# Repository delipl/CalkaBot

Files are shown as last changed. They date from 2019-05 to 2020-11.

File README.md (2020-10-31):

# CalkaBot

CałkaBots are robots created by Jakub Kuziemski and Jakub Delicat. The first one CałkaBot 1.0 was made in 2018 for miniSUMO competition in UTP in Bydgoszcz. We were first grade students then, and we weren't experienced enough, so it was a huge surprise when we got to a semifinal group. The second one, CałkaBot 2.0, was made the following year and won a special prize in Bydgoszcz. We have been appreciated for the progress and for a PCB board project made by Deli. With both robots, improved to versions 1.1 and 2.1, we have gone to Baltic Robo Battles, to face up univeristy students. We weren't surprised when we have lost most of the battles, but CałkaBots were hard opponent many times. We have even managed to win some of the battles against students of technical universities.

# Our Team
- [Jakub Kuziemski (@JakubKivi)](https://github.com/JakubKivi)
- [Jakub Delicat (@delipl)](https://github.com/delipl)
- [Adam Wieczarek (@AWieczarek)](https://github.com/AWieczarek)

CałkaBots 3d0 and 3k0 are comming.

# Hardware and software tips
To program BluePill from hid bootloader it is nessesery to refresh flash data in STM32CUBE

To run STM32CubeProgrammer on linux it is nessesery to install java zulu

Ahh.. To run EAGLE on linux it is nessesery to copy library to $EAGLE/lib folder 
`sudo cp /usr/lib/x86_64-linux-gnu/libxcb-dri3.so.0 lib/
`

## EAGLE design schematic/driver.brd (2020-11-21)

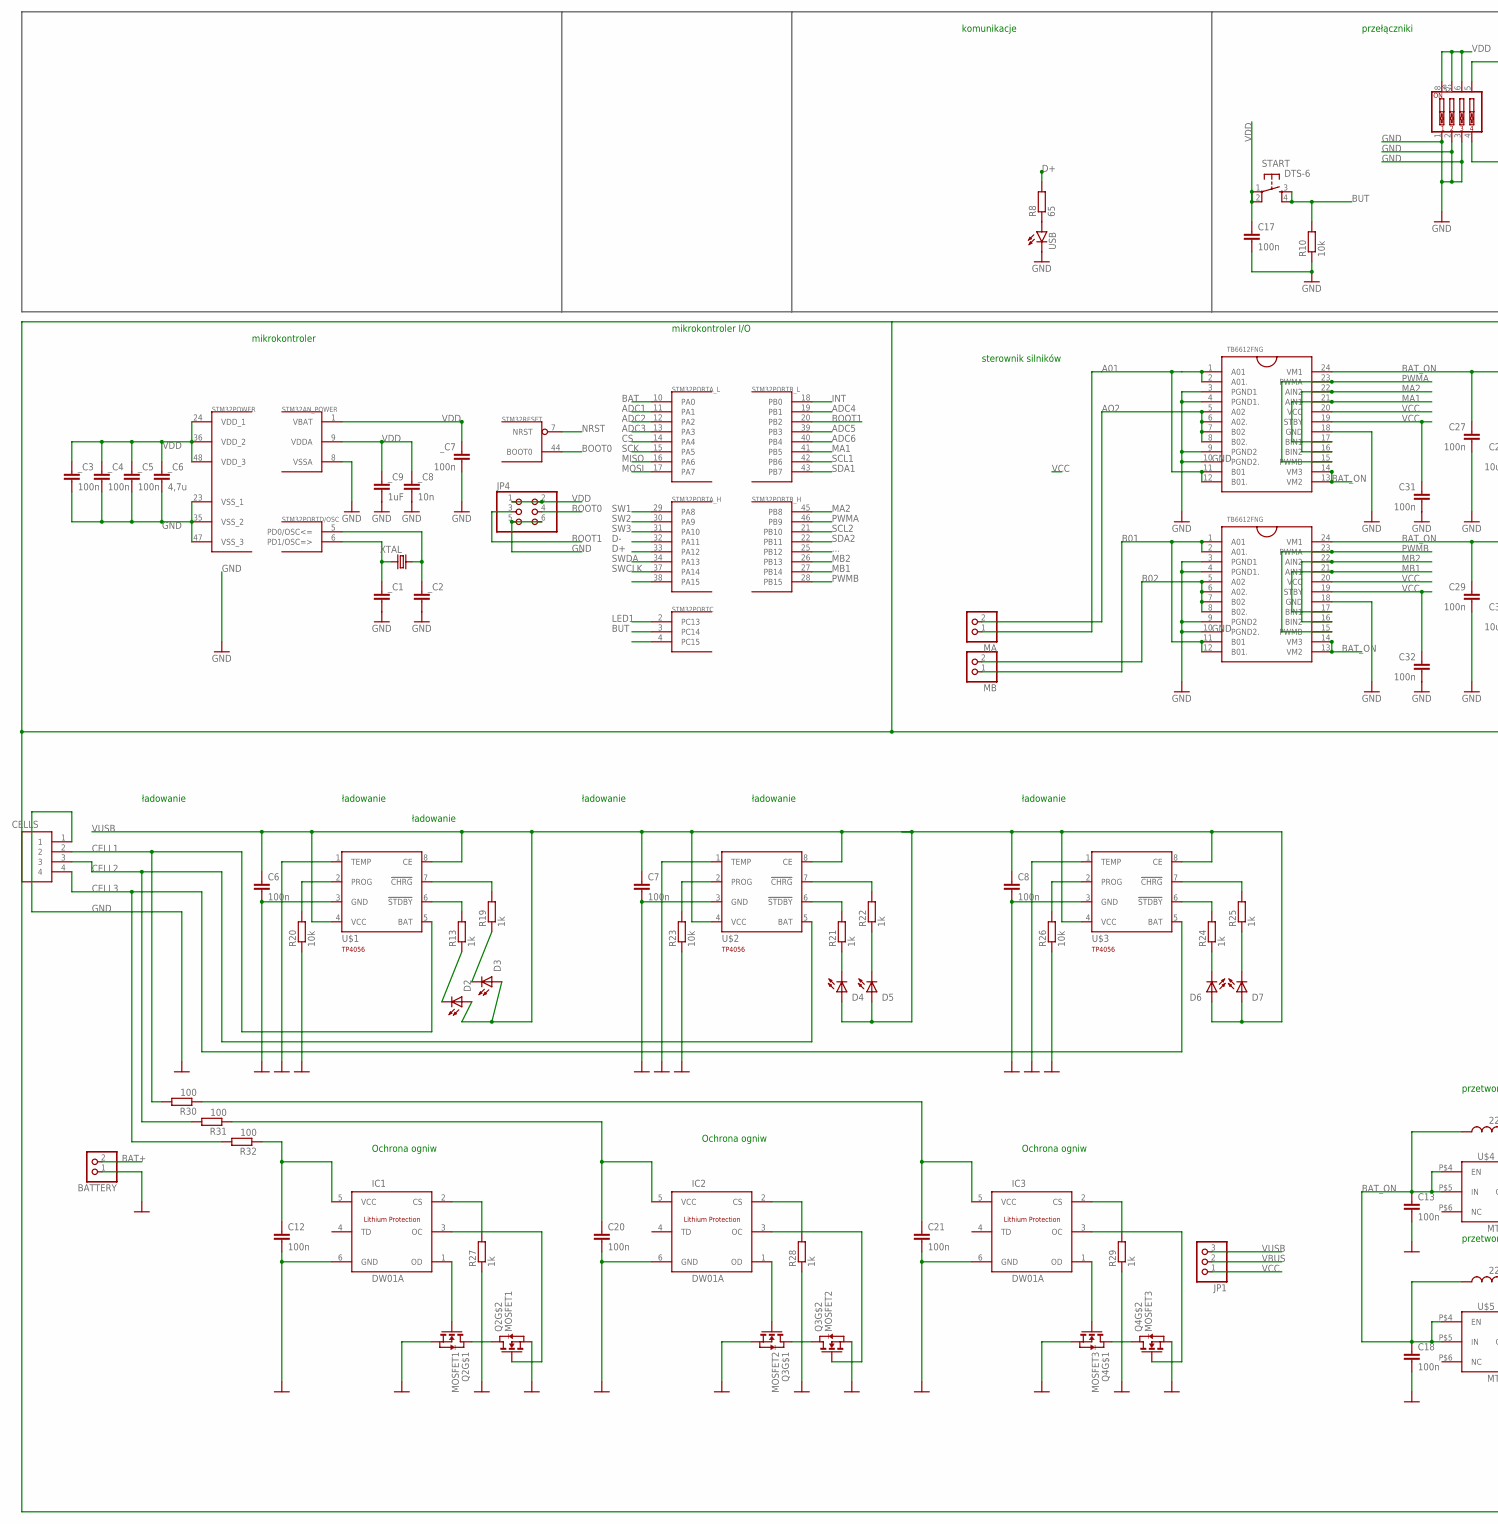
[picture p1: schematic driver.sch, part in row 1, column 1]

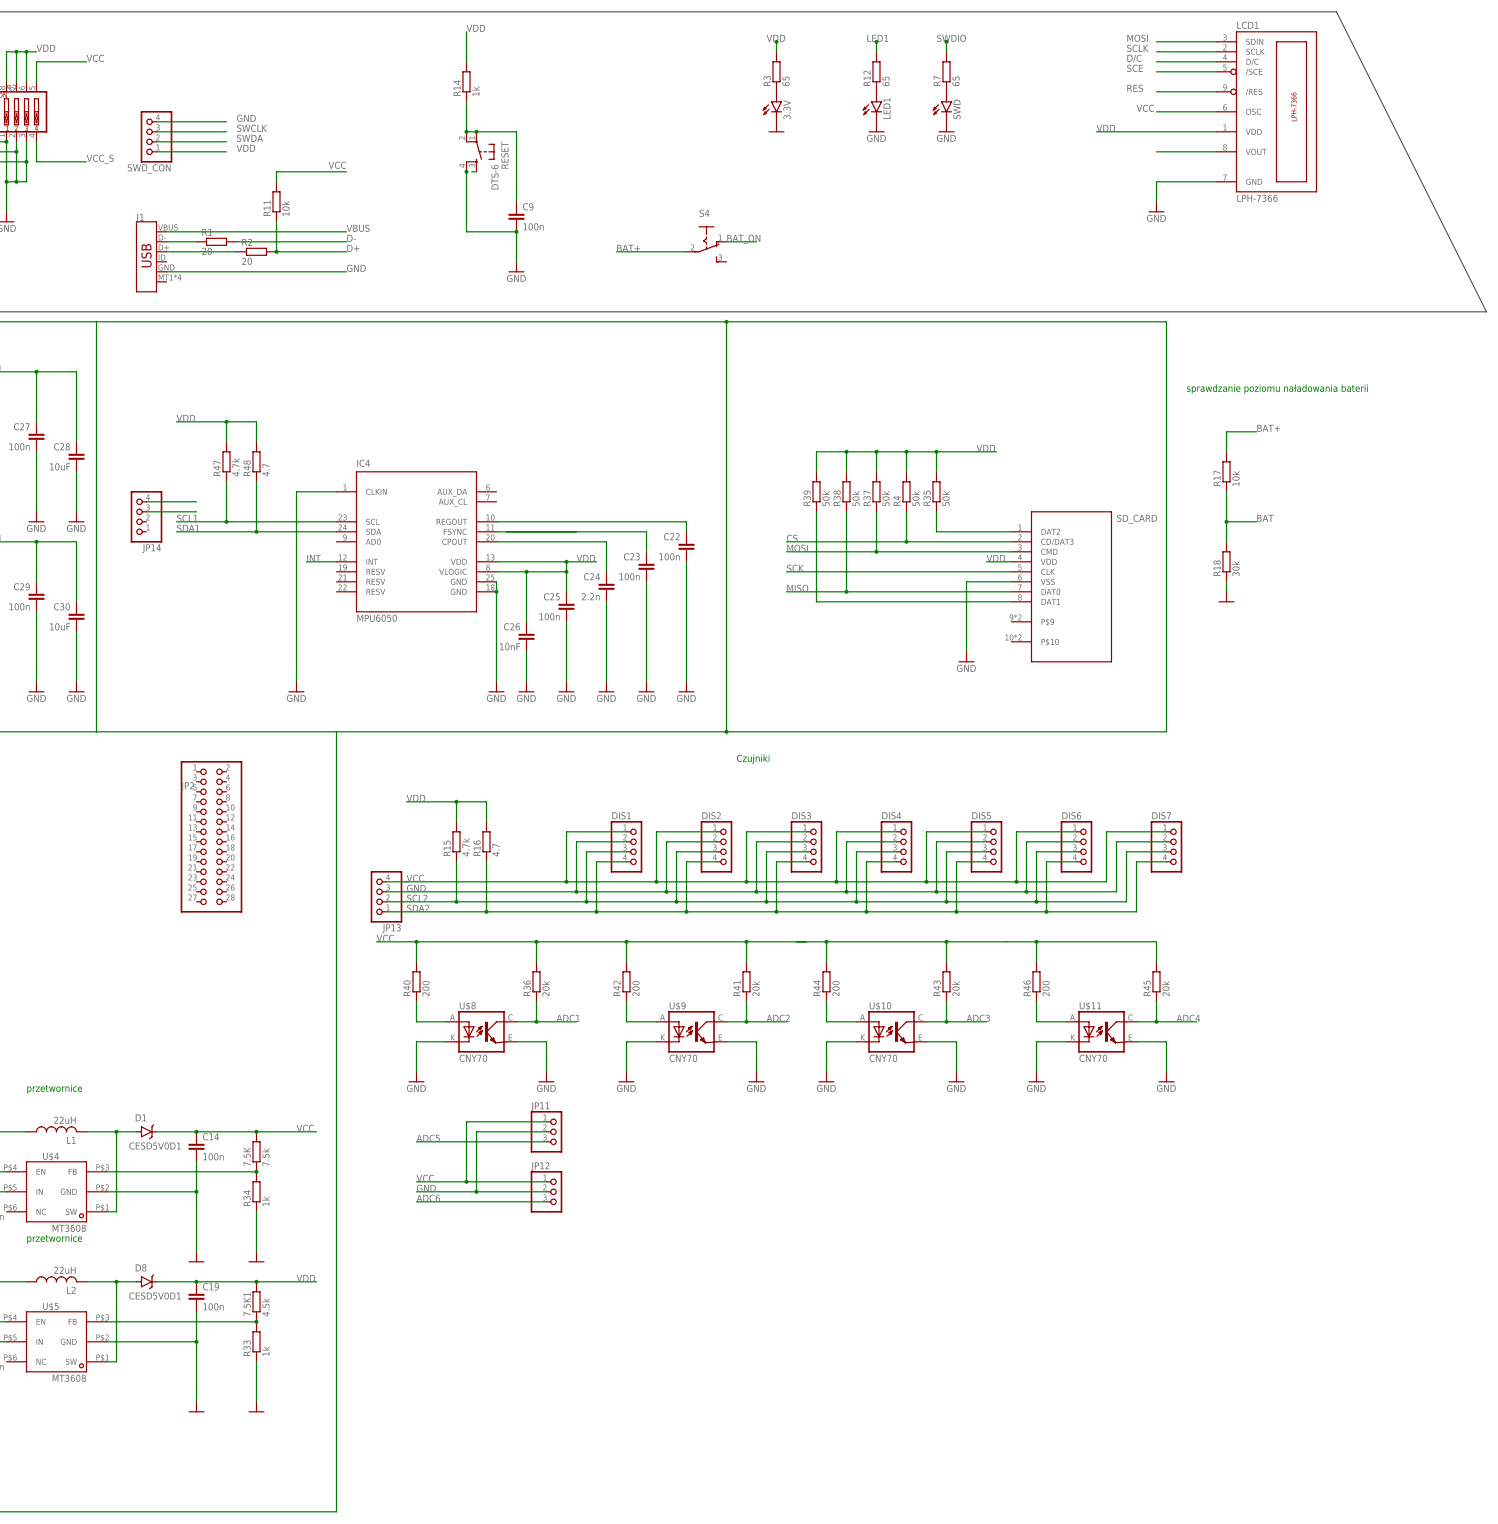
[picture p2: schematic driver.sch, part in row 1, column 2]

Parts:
3.3V: LEDCHIPLED_0805; CHIPLED_0805
7.5K: 7.5k; R0805
7.5K1: 4.5k; R0805
BATTERY: PINHD-1X2; 1X02
C6, C7, C8, C9, C12, C13, C14, C17, C18, C19, C20, C21, C22, C23, C25, C27, C29, C31, C32: 100n; C0603
C24: 2.2n; C0603
C26: 10nF; C0603
C28, C30: 10uF; C0603
CELLS: S4B-XH-A(LF)(SN); HDR-04/RA
D1, D8: CESD5V0D1; SOD-123
D2, D3, D4, D5, D6, D7: LEDCHIPLED-0603-TTW; CHIPLED-0603-TTW
DIS1, DIS2, DIS3, DIS4, DIS5, DIS6, DIS7: PINHD-1X4; 1X04
IC1, IC2, IC3: DW01A; SOT23-6
IC4: MPU6050; QFN50P400X400X95-25T265X275N
J1: USB_MICRO-B_SMT; USB-MICROB
JP1, JP11, JP12: PINHD-1X3; 1X03
JP2: PINHD-2X14; 2X14
JP4: PINHD-2X3; 2X03
JP13, JP14: PINHD-1X4; 1X04
L1, L2: 22uH; L1812
LCD1: LPH-7366
LED1: LEDCHIPLED_0805; CHIPLED_0805
MA: PINHD-1X2/90; 1X02/90
MB: PINHD-1X2/90; 1X02/90
Q2: MOSFET1; SOT363
Q3: MOSFET2; SOT363
Q4: MOSFET3; SOT363
R1, R2: 20; R0805
R3, R7, R8, R12: 65; R0805
R4, R35, R37, R38, R39: 50k; R0805
R10, R11, R17, R20, R23, R26: 10k; R0805
R13, R14, R19, R21, R22, R24, R25, R27, R28, R29, R33, R34: 1k; R0805
R15, R47: 4.7k; R0805
R16, R48: 4.7; R0805
R18: 30k; R0805
R30, R31, R32: 100; R0805
R36, R41, R43, R45: 20k; R0805
R40, R42, R44, R46: 200; R0805
RESET: DTS-6
S2: SW_DIP-4; EDG-04
S4: 255SB
SD_CARD: 693071010811
START: DTS-6
STM32: STM32F10XCXT6; TQFP48
SWD: LEDCHIPLED_0805; CHIPLED_0805
SWD_CON: PINHD-1X4; 1X04
U$1, U$2, U$3: TP4056; SOT23-8
U$4, U$5: MT3608SOT23-6; SOT23-6
U$6, U$7: TB6612FNG; SSOP24
U$8, U$9, U$10, U$11: CNY70; 4
USB: LEDCHIPLED_0805; CHIPLED_0805
XTAL: KX-7; 3.2X2.5_KX-7
_C1, _C2: C-EUC0603; C0603
_C3, _C4, _C5, _C7: 100n; C0603
_C6: 4,7u; C0603
_C8: 10n; C0603
_C9: 1uF; C0603

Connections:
...: STM32.25 (PB12)
A01: MA.1, U$6.1 (A01), U$6.2 (A01.), U$6.11 (B01), U$6.12 (B01.)
ADC1: R36.1, STM32.11 (PA1), U$8.C (COL)
ADC2: R41.1, STM32.12 (PA2), U$9.C (COL)
ADC3: R43.1, STM32.13 (PA3), U$10.C (COL)
ADC4: R45.1, STM32.19 (PB1), U$11.C (COL)
ADC5: JP11.3, STM32.39 (PB3)
ADC6: JP12.3, STM32.40 (PB4)
AO2: MA.2, U$6.5 (A02), U$6.6 (A02.), U$6.7 (B02), U$6.8 (B02.)
B01: MB.1, U$7.1 (A01), U$7.2 (A01.), U$7.11 (B01), U$7.12 (B01.)
B02: MB.2, U$7.5 (A02), U$7.6 (A02.), U$7.7 (B02), U$7.8 (B02.)
BAT: R17.1, R18.2, STM32.10 (PA0)
BAT+: BATTERY.2, R17.2, S4.2
BAT_ON: C13.1, C18.1, C27.1, C28.1, C29.1, C30.1, L1.1, L2.1, S4.1 (O), U$4.P$4 (EN), U$4.P$5 (IN), U$5.P$4 (EN), U$5.P$5 (IN), U$6.13 (VM2), U$6.14 (VM3), U$6.24 (VM1), U$7.13 (VM2), U$7.14 (VM3), U$7.24 (VM1)
BOOT0: JP4.4, STM32.44 (BOOT0)
BOOT1: JP4.3, STM32.20 (PB2)
BUT: R10.2, START.3, START.4, STM32.3 (PC14)
CELL1: CELLS.2, R30.2, U$1.5 (BAT)
CELL2: CELLS.3, R31.2, U$2.5 (BAT)
CELL3: CELLS.4, R32.2, U$3.5 (BAT)
CS: R4.1, SD_CARD.2 (CD/DAT3), STM32.14 (PA4)
D+: R2.2, R8.2, R11.1, STM32.33 (PA12)
D-: R1.2, STM32.32 (PA11)
D/C: LCD1.4 (D/C)
GND: 3.3V.C, BATTERY.1, C6.2, C7.2, C8.2, C9.2, C12.2, C13.2, C14.2, C17.2, C18.2, C19.2, C20.2, C21.2, C22.2, C23.2, C24.2, C25.2, C26.2, C27.2, C28.2, C29.2, C30.2, C31.2, C32.2, CELLS.1, DIS1.2, DIS2.2, DIS3.2, DIS4.2, DIS5.2, DIS6.2, DIS7.2, IC1.6 (GND), IC2.6 (GND), IC3.6 (GND), IC4.1 (CLKIN), IC4.18 (GND), IC4.25 (GND), J1.GND, JP4.5, JP4.6, JP11.2, JP12.2, JP13.3, LCD1.7 (GND), LED1.C, Q2.1 (S), Q2.4 (S), Q3.1 (S), Q3.4 (S), Q4.1 (S), Q4.4 (S), R10.1, R18.1, R20.1, R23.1, R26.1, R27.1, R28.1, R29.1, R33.1, R34.1, RESET.4, S2.1, S2.2, S2.3, SD_CARD.6 (VSS), STM32.8 (VSSA), STM32.23 (VSS_1), STM32.35 (VSS_2), STM32.47 (VSS_3), SWD.C, SWD_CON.4, U$1.1 (TEMP), U$1.3 (GND), U$2.1 (TEMP), U$2.3 (GND), U$3.1 (TEMP), U$3.3 (GND), U$4.P$2 (GND), U$5.P$2 (GND), U$6.3 (PGND1), U$6.4 (PGND1.), U$6.9 (PGND2), U$6.10 (PGND2.), U$6.18 (GND), U$7.3 (PGND1), U$7.4 (PGND1.), U$7.9 (PGND2), U$7.10 (PGND2.), U$7.18 (GND), U$8.E (EMI), U$8.K (C), U$9.E (EMI), U$9.K (C), U$10.E (EMI), U$10.K (C), U$11.E (EMI), U$11.K (C), USB.C, _C1.2, _C2.2, _C3.2, _C4.2, _C5.2, _C6.2, _C7.2, _C8.2, _C9.2
INT: IC4.12 (INT), STM32.18 (PB0)
LED1: R12.2, STM32.2 (PC13)
MA1: STM32.41 (PB5), U$6.17 (BIN1), U$6.21 (AIN1)
MA2: STM32.45 (PB8), U$6.16 (BIN2), U$6.22 (AIN2)
MB1: STM32.27 (PB14), U$7.17 (BIN1), U$7.21 (AIN1)
MB2: STM32.26 (PB13), U$7.16 (BIN2), U$7.22 (AIN2)
MISO: R38.1, SD_CARD.7 (DAT0), STM32.16 (PA6)
MOSI: LCD1.3 (SDIN), R37.1, SD_CARD.3 (CMD), STM32.17 (PA7)
unnamed: R40.1, U$8.A
unnamed: STM32.5 (PD0/OSC<=), XTAL.1, _C2.1
unnamed: STM32.6 (PD1/OSC=>), XTAL.3 (2), _C1.1
unnamed: J1.D+, R2.1
unnamed: J1.D-, R1.1
unnamed: R22.2, U$2.7 (!CHRG)
unnamed: R13.2, U$1.6 (!STDBY)
unnamed: 3.3V.A, R3.1
unnamed: R7.1, SWD.A
unnamed: D2.C@1 (C), R13.1
unnamed: R19.2, U$1.7 (!CHRG)
unnamed: D3.C@1 (C), R19.1
unnamed: R20.2, U$1.2 (PROG)
unnamed: R21.2, U$2.6 (!STDBY)
unnamed: D4.C@1 (C), R21.1
unnamed: D5.C@1 (C), R22.1
unnamed: R23.2, U$2.2 (PROG)
unnamed: R25.2, U$3.7 (!CHRG)
unnamed: R24.2, U$3.6 (!STDBY)
unnamed: D6.C@1 (C), R24.1
unnamed: D7.C@1 (C), R25.1
unnamed: R26.2, U$3.2 (PROG)
unnamed: IC1.1 (OD), Q2.2 (G)
unnamed: IC1.3 (OC), Q2.5 (G)
unnamed: C12.1, IC1.5 (VCC), R32.1
unnamed: IC1.2 (CS), R27.2
unnamed: Q2.3 (D), Q2.6 (D)
unnamed: IC2.2 (CS), R28.2
unnamed: C20.1, IC2.5 (VCC), R31.1
unnamed: IC2.1 (OD), Q3.2 (G)
unnamed: IC2.3 (OC), Q3.5 (G)
unnamed: Q3.3 (D), Q3.6 (D)
unnamed: IC3.2 (CS), R29.2
unnamed: C21.1, IC3.5 (VCC), R30.1
unnamed: IC3.1 (OD), Q4.2 (G)
unnamed: IC3.3 (OC), Q4.5 (G)
unnamed: Q4.3 (D), Q4.6 (D)
unnamed: C22.1, IC4.10 (REGOUT)
unnamed: C24.1, IC4.20 (CPOUT)
unnamed: D1.A, L1.2, U$4.P$1 (SW)
unnamed: D8.A, L2.2, U$5.P$1 (SW)
unnamed: 7.5K1.1, R33.2, U$5.P$3 (FB)
unnamed: 7.5K.1, R34.2, U$4.P$3 (FB)
unnamed: LED1.A, R12.1
unnamed: R8.1, USB.A
unnamed: R42.1, U$9.A
unnamed: R35.1, SD_CARD.1 (DAT2)
unnamed: R44.1, U$10.A
unnamed: R39.1, SD_CARD.8 (DAT1)
unnamed: R43.2, R44.2
unnamed: R46.1, U$11.A
unnamed: R45.2, R46.2
NRST: C9.1, R14.1, RESET.1, RESET.2, STM32.7 (NRST)
PC15: STM32.4 (PC15)
PWMA: STM32.46 (PB9), U$6.15 (PWMB), U$6.23 (PWMA)
PWMB: STM32.28 (PB15), U$7.15 (PWMB), U$7.23 (PWMA)
RES: LCD1.9 (/RES)
SCE: LCD1.5 (/SCE)
SCK: SD_CARD.5 (CLK), STM32.15 (PA5)
SCL1: IC4.23 (SCL), R47.1, STM32.42 (PB6)
SCL2: DIS1.3, DIS2.3, DIS3.3, DIS4.3, DIS5.3, DIS6.3, DIS7.3, JP13.2, R15.1, STM32.21 (PB10)
SCLK: LCD1.2 (SCLK)
SDA1: IC4.24 (SDA), R48.1, STM32.43 (PB7)
SDA2: DIS1.4, DIS2.4, DIS3.4, DIS4.4, DIS5.4, DIS6.4, DIS7.4, JP13.1, R16.1, STM32.22 (PB11)
SW1: STM32.29 (PA8)
SW2: STM32.30 (PA9)
SW3: STM32.31 (PA10)
SWCLK: STM32.37 (PA14), SWD_CON.3
SWDA: STM32.34 (PA13), SWD_CON.2
SWDIO: R7.2
TDI: STM32.38 (PA15)
VBUS: J1.VBUS, JP1.2
VCC: 7.5K.2, C14.1, C31.1, C32.1, D1.C, DIS1.1, DIS2.1, DIS3.1, DIS4.1, DIS5.1, DIS6.1, DIS7.1, JP1.1, JP11.1, JP12.1, JP13.4, LCD1.6 (OSC), R11.2, R36.2, R40.2, R41.2, R42.2, S2.5, U$6.19 (STBY), U$6.20 (VCC), U$7.19 (STBY), U$7.20 (VCC)
VCC_S: S2.4
VDD: 7.5K1.2, C17.1, C19.1, C25.1, C26.1, D8.C, IC4.8 (VLOGIC), IC4.13 (VDD), JP4.1, JP4.2, LCD1.1 (VDD), R3.2, R4.2, R14.2, R15.2, R16.2, R35.2, R37.2, R38.2, R39.2, R47.2, R48.2, S2.6, S2.7, S2.8, SD_CARD.4 (VDD), START.1, START.2, STM32.1 (VBAT), STM32.9 (VDDA), STM32.24 (VDD_1), STM32.36 (VDD_2), STM32.48 (VDD_3), SWD_CON.1, _C3.1, _C4.1, _C5.1, _C6.1, _C7.1, _C8.1, _C9.1
VUSB: C6.1, C7.1, C8.1, D2.A@1 (A), D3.A@1 (A), D4.A@1 (A), D5.A@1 (A), D6.A@1 (A), D7.A@1 (A), JP1.3, U$1.4 (VCC), U$1.8 (CE), U$2.4 (VCC), U$2.8 (CE), U$3.4 (VCC), U$3.8 (CE)

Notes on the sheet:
komunikacje
przełączniki
mikrokontroler
mikrokontroler I/O
sterownik silników
sprawdzanie poziomu naładowania baterii
ładowanie
Ochrona ogniw
przetwornice
Czujniki

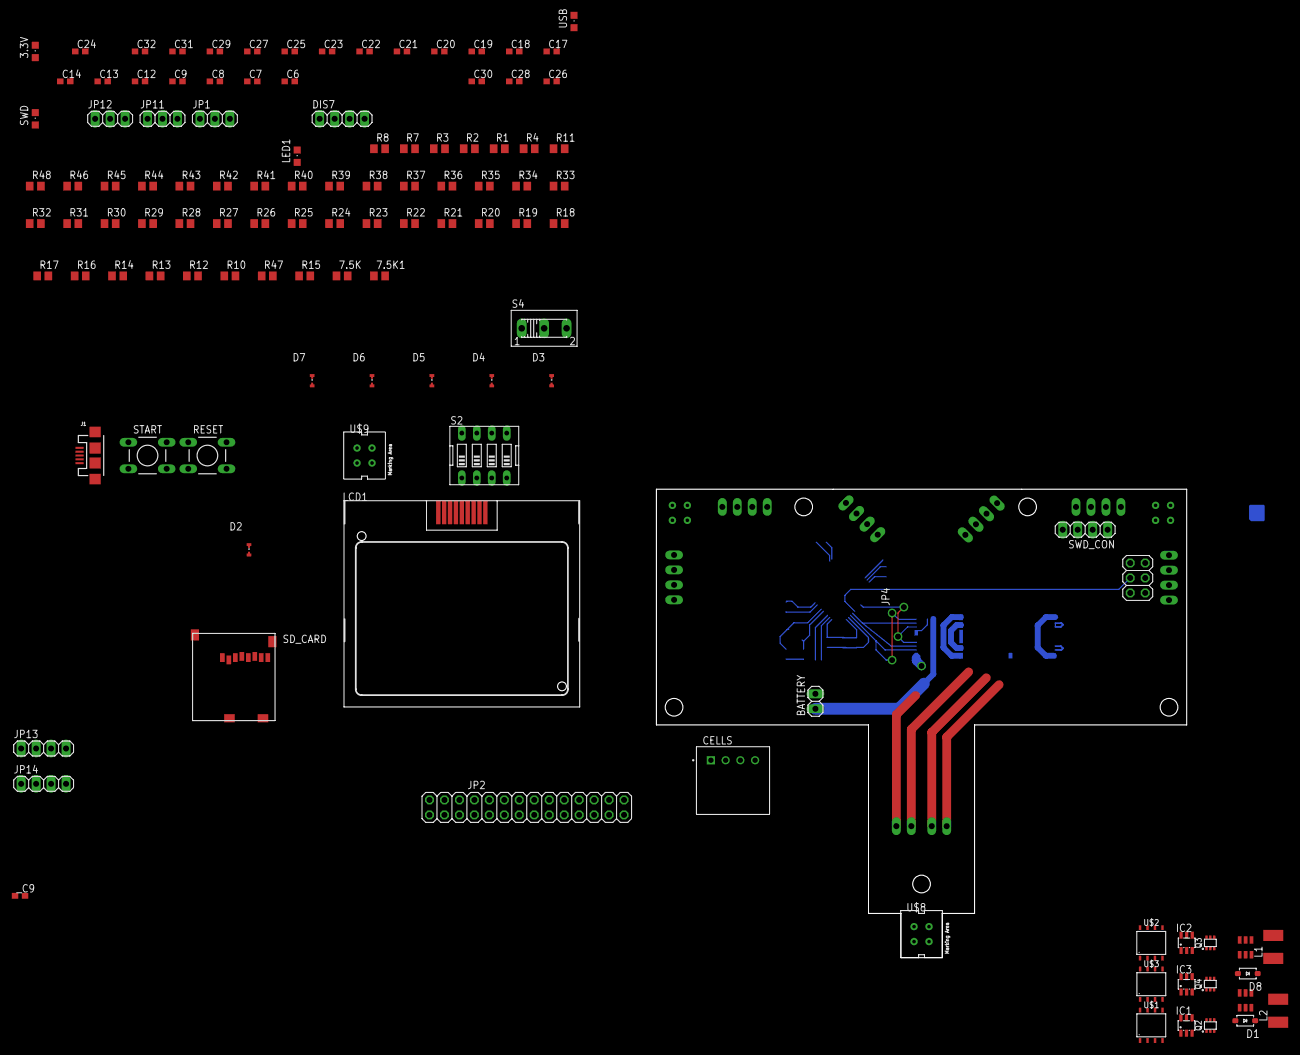
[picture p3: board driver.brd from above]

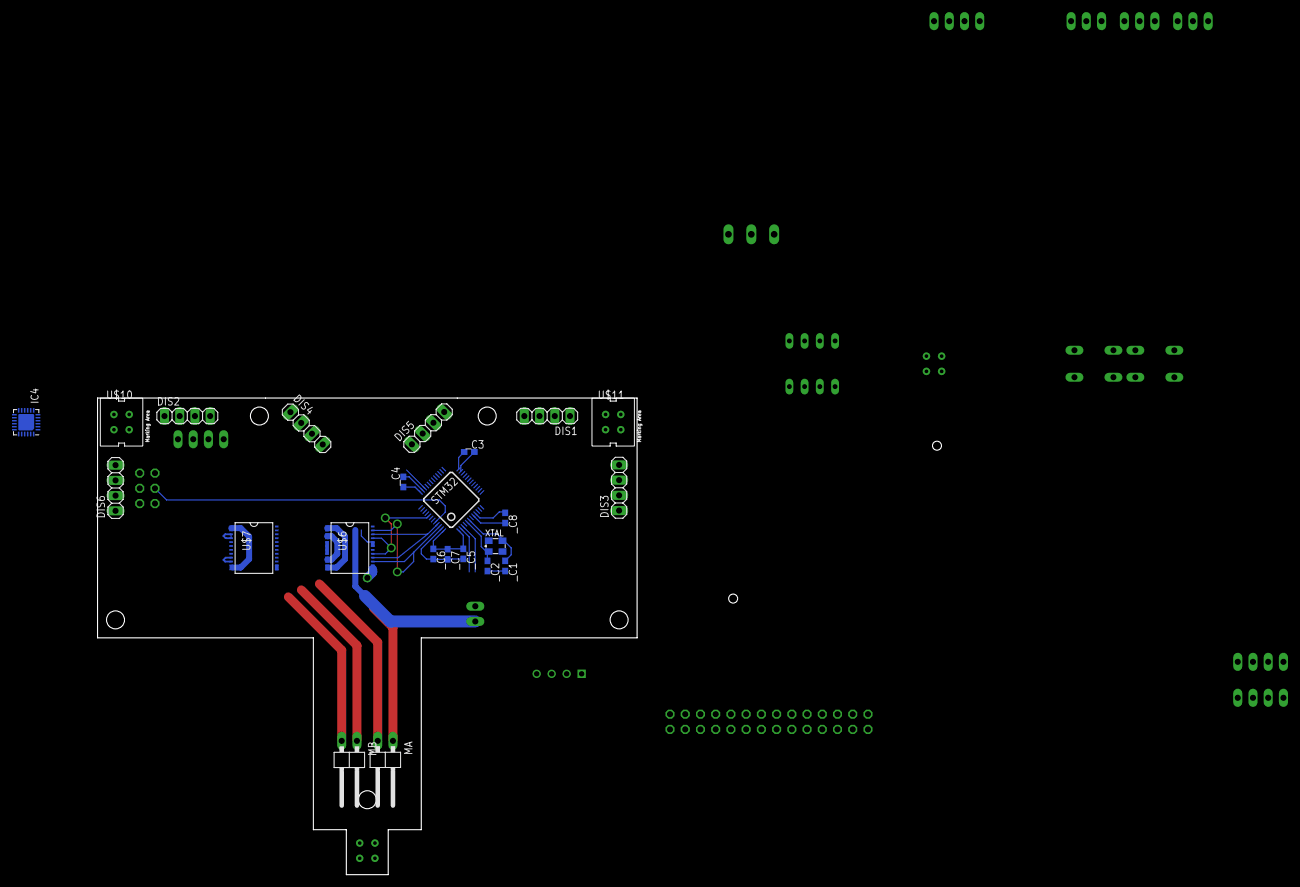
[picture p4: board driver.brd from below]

Board: 2 copper layers, 90.0 x 79.5 mm, 139 parts (23 on the bottom side), 97 nets.

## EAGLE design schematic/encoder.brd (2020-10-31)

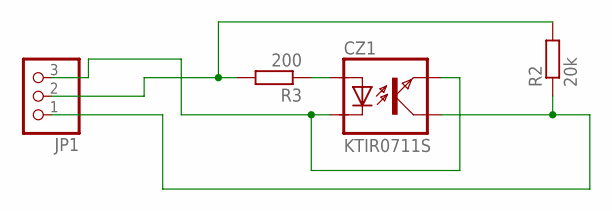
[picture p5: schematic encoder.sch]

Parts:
CZ1: KTIR0711S; TOP
JP1: PINHD-1X3; 1X03
R2: 20k; R0805
R3: 200; R0805

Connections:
unnamed: CZ1.EMITER, CZ1.KATODA, JP1.3
unnamed: CZ1.KOLEKTOR, JP1.1, R2.1
unnamed: CZ1.ANODA, R3.1
unnamed: JP1.2, R2.2, R3.2

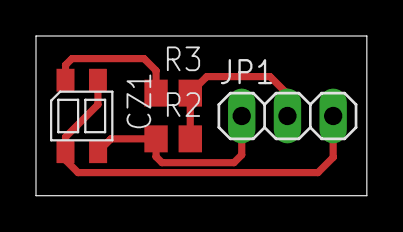
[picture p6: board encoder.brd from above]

Board: 2 copper layers, 18.4 x 8.9 mm, 4 parts (0 on the bottom side), 4 nets.

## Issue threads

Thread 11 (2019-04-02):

Grubość ścieżek

delipl, 2019-04-02:
Ścieżki:
- Gnd
- 7.4V
- Do silników

Powinny być grubsze!!!

delipl, 2020-10-10:
Wersje CałkaBot 3 uwzględniły prądy w ścieżkach.

Closed 2020-10-10.

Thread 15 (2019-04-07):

Sprawdzanie poziomu naładowania baterii

delipl, 2019-04-07:
AVCC do 7.4V i sprawdzać czy jest bateria naładowana

delipl, 2020-10-11:
fixed 893b0ed

Closed 2020-10-11.

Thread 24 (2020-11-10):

STM32

delipl, 2020-11-10:
Wstawić na nowo stma

delipl, 2020-11-13:
fixed

Closed 2020-11-13.

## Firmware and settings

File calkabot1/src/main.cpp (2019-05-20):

#include "header.h"

void setup(){

	irrecv.enableIRIn();
	//czujniki odległości
	pinMode(sensorF, INPUT);
	pinMode(sensorFL, INPUT);
	pinMode(sensorFR, INPUT);
	pinMode(sensorB, INPUT);
	pinMode(sensorBR, INPUT);
	pinMode(sensorBL, INPUT);

	//silnik
	pinMode(AIN1, OUTPUT);
	pinMode(AIN2, OUTPUT);
	pinMode(BIN1, OUTPUT);
	pinMode(BIN2, OUTPUT);

	//Led
	pinMode(9, OUTPUT);
	digitalWrite(9,HIGH);

	for(int i = 0; i < 5; i++){
		digitalWrite(9, 0);
		delay(100);
		digitalWrite(9, 1);
		delay(100);
	}
}



void loop(){
bool play=1;
byte check = irRemoute();
 if (check != 0)
{
	play=1;
  // Tutaj podajemy co ma wykonać dalej z zmienną check jeżeli nie jest ona zerem
}
//play=1;
while(play){//nzfs
		while (true){
			if(!floor()){
				while(digitalRead(sensorB)==0) go(0, 0);
				while(digitalRead(sensorF)==0) go(0, 1);
				if(digitalRead(sensorFR)==0) go(3, 1);
				else if(digitalRead(sensorFL)==0) go(2, 1);
				else if(digitalRead(sensorBR)==0) go(3, 0);
				else if(digitalRead(sensorBL)==0) go(2, 0);
				else spin();
			}else if(floorFront()){
				go(0, 0);
				delay(100);
			}else if(floorBack()){
				go(0, 1);
				delay(100);
			}
		}
 	}

}

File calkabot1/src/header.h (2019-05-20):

#include "Arduino.h"
#include "../lib/IRremote/IRremote.h"

IRrecv irrecv(8);
decode_results results;

//distance sensor front
#define sensorF 0
#define sensorFL 3
#define sensorFR 2
#define sensorB 7
#define sensorBL 1
#define sensorBR 4

#define floorBL 13
#define floorBR 12
#define floorFL 11
#define floorFR 10		//nie jestem pewny czy dobrze są lewy prawy ale to nieważne

//motor

#define AIN1 12
#define AIN2 13
#define BIN1 10
#define	BIN2 11

void error(int errorNr){
	digitalWrite(AIN1, 0);
	digitalWrite(AIN2, 0);
  digitalWrite(BIN1, 0);
  digitalWrite(BIN2, 0);

	while(true){
		for (int i = 0; i < errorNr; ++i){
			digitalWrite(9,LOW);
			delay(200);
			digitalWrite(9,HIGH);
			delay(200);
		}
		delay(2000);
	}
}

bool floorFront(){
//	if(analogRead(floorFL)>10||analogRead(floorFR)>10) retirn 1;
	return 0;
}

bool floorBack(){
//	if(analogRead(floorBL)>10||analogRead(floorBR)>10) retirn 1;
	return 0;
}

bool floor(){
	if(floorFront()||floorBack())return 1;
	return 0;
}

void slowStop(){
  digitalWrite(AIN1, 0);
  digitalWrite(AIN2, 0);
  digitalWrite(BIN1, 0);
  digitalWrite(BIN2, 0);
}

void hardStop(){
  digitalWrite(AIN1, 1);
  digitalWrite(AIN2, 1);
  digitalWrite(BIN1, 1);
  digitalWrite(BIN2, 1);
}

void goForward(){
  digitalWrite(AIN1, 0);
  digitalWrite(AIN2, 1);
  digitalWrite(BIN1, 0);
  digitalWrite(BIN2, 1);
}

void goBackward(){
  digitalWrite(AIN1, 1);
  digitalWrite(AIN2, 0);
  digitalWrite(BIN1, 1);
  digitalWrite(BIN2, 0);
}

void go(int x, bool direction){ //0-full; 1-optimal; 2-left; 3-right
	if(x==0){
		direction?goForward():goBackward();
	}
	else if(x==1){
		if(direction){
			goForward();
			delay(1);
			slowStop();
			delay(3);
		}else{
			goBackward();
			delay(1);
			slowStop();
			delay(3);
		}
	}else if(x==2){
		if(direction){
			slowStop();
			digitalWrite(AIN2, 1);
			delay(1);
		}else{
			slowStop();
			digitalWrite(BIN1, 1);
			delay(1);
		}
	}else if(x==3){
		if(direction){
			slowStop();
			digitalWrite(BIN2, 1);
			delay(1);
		}else{
			slowStop();
			digitalWrite(AIN1, 1);
			delay(1);
		}
	}

}

void spin(){
    digitalWrite(AIN1, 1);
    digitalWrite(AIN2, 0);
    digitalWrite(BIN1, 0);
    digitalWrite(BIN2, 1);
    delay(1);
    slowStop();
    delay(1);
}

byte irRemoute ()
{
byte dane=0;
  while(dane==0)
{
   if (irrecv.decode(&results)) // sprawdza, czy otrzymano sygna� IR
{
       unsigned long odczyt = results.value; // sygnał zapisuje jako odczyt
switch (odczyt)
       {
case 1857: //power
  dane = 1;
break;
case 3905: //eneter
	dane = 1;
break;
case 16711935: //eneter
	dane = 1;
break;
case 3785549847:
	dane = 1;
break;

default:
         dane=0;
}
      irrecv.resume(); // reseruje czujnik
}
   else
{
    dane=0;
}
  }
return dane ;
}

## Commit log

2018-10-02 copied Eagle project
    [schemat.brd, schemat.sch]
2018-10-03 added resonator
    [schemat.brd, schemat.sch]
2018-10-21 Powiększone dziurki
    [schemat.brd, schemat.sch]
2018-11-07 przyciski i usunalem isp
    [schemat.brd, schemat.sch]
2018-11-08 Dodałem stabilizator i filtrację stabilizator i przyciski
    [schemat.brd, schemat.sch]
2018-11-08 Dodałem filtr do zasialania silników i do sterownika
    [schemat.brd, schemat.sch]
2018-11-08 podłączenie przycisków teraz
    [schemat.brd, schemat.sch]
2018-11-16 nie ma miejsca na usb, pcb prawie skończone
    [schemat.brd, schemat.sch]
2018-11-16 potrzebne wyjscia do czujnikow odleglosci i płytka z gniazdem usb
    [schemat.brd, schemat.sch]
2018-11-21 niezapisane rzeczt
    [schemat.brd, schemat.sch]
2018-11-22 dodalem dipy
    [schemat.brd, schemat.sch]
2018-11-22 połączono wszystkie VCC i GND
    [schemat.brd]
2018-11-22 dodano diode
    [schemat.brd, schemat.sch]
2018-11-22 chyba skończyłem
    [schemat.brd]
2018-11-22 end 3x
    [schemat.brd]
2018-12-08 poprawki wprowadzone, zmiana dipa z 3 na 4, przesunięcie włącznika zasilania
    [schemat.brd, schemat.sch]
2018-12-09 dodałem gniazdo B, włącznik przyłączony z trybami
    [schemat.brd, schemat.sch]
2018-12-09 zapomiałem o ziemi
    [schemat.brd]
2018-12-09 Cały robot z kołami, redukcja miejsca
    [schemat.brd]
2018-12-09 redukcja miejsca, przygotowywanie pod dodawnie transoptora smd
    [schemat.brd]
2018-12-09 dodałem koła i poczne ściany
    [schemat.brd, schemat.sch]
2018-12-09 nie starcza mi miejsca nie wiem o co cmon
    [schemat.brd]
2018-12-09 Mogę już podłączyć na transoptory
    [schemat.brd]
2018-12-10 Podłączone transoptory, trzeba rozkminić jak podłączyć gniazda
    [schemat.brd, schemat.sch]
2018-12-13 przesunięte ścieżki i elementy żeby nie zasłaniały silniki
    [schemat.brd]
2018-12-13 Ładnie opisane od góry
    [schemat.brd, schemat.sch]
2018-12-13 dodane pinheady dla czujników odległości, teraz trzeba je podłączyć
    [schemat.brd, schemat.sch]
2018-12-25 tylko rozmieściłem
    [schemat.brd]
2019-01-23 polaczenia plytki skonczone teraz tylko poligony
    [schemat.brd]
2019-01-23 dodanie wymiarow
    [schemat.brd]
2019-01-23 porobione paddingi
    [schemat.brd]
2019-02-04 plytka skonczona zrobione poligony
    [schemat.brd, schemat.sch]
2019-02-04 niezapisane zmieny :D
    [schemat.brd]
2019-02-04 zmiana nazwy folderu
    [schemat.brd, schemat.sch]
2019-03-03 powiekszylem pierscien viasow
    [schemat.brd]
2019-03-03 zmiana viasow na 0.5/1.3
    [schemat.brd]
2019-04-18 poprawa wyglądu schematu
    [schemat.sch]
2019-04-19 pinMode przed Ledami
2019-04-19 Pwm fix, usb dla windowsa
    [header.h]
2019-04-20 Sprawdzanie switchy i podzial na podprogramy
2019-04-20 dodano funkcje error (wymiguje numer błędu)
    [header.h]
2019-04-20 pierwszy error(i chyba ostatni ale moze sie przyda potem)
    [main.cpp]
2019-04-21 oscylatop + ISP
    [schemat.sch]
2019-04-22 Usunięcie syfu z mainu, przeniesienie floorSensors() do motor.h, przepisanie program0(), dodanie toSeeFront()
2019-04-24 Zmiana programatora na USBasp Naprawnie funkcji `error()` Dodanie kolejnych plików kolejnych programów
    [header.h, main.cpp]
2019-04-24 zmiana pwm w silnikach
2019-05-20 przeniesienie plikow do calkabot2
    [schemat.brd, schemat.sch]
2019-05-20 dodanie calkabot1 do repo
    [calkabot1.brd, calkabot1.sch]
2020-04-06 init calakabot3.0
    [driver.brd, driver.sch]
2020-04-23 Posegregowanie projektu, rozdzielienie robotów na dwie wersje
    [driver.brd, driver.sch]
2020-05-17 teraz schemat wygląda ładnie
    [driver.brd, driver.sch]
2020-09-29 Jtag ssie, zrobiłem SWD. Zmiana płyki. pomniejszenie dodanie resetu itd.
    [driver.brd, driver.sch]
2020-10-06 Distans sensor work
2020-10-07 Adding I2C pull-up resistors, 5V on board, change package for LM1117, PB2 (BOOT1) short to GND
    [driver.brd, driver.sch]
2020-10-08 Adding motor outputs
    [driver.brd, driver.sch]
2020-10-08 Change board
    [driver.brd, driver.sch]
2020-10-11 added battery voltage checker and led
    [driver.brd, driver.sch]
2020-10-11 added switch to disconnect voltage from sensors
    [driver.brd, driver.sch]
2020-10-11 comments on schematic, added led for I2C supply
    [driver.brd, driver.sch]
2020-10-12 Linking in arduino works only with .h files,
2020-10-12 Acceleromoeter works fine
2020-10-12 Accelerometer shows angle thanks to example for MPU6050 from https://github.com/jrowberg/i2cdevlib
2020-10-12 Added schematic for encoder
    [encoder.brd, encoder.sch]
2020-10-13 pcb design
    [driver.brd, driver.sch]
2020-10-15 change code accoding to the prototype of 3d0
2020-10-15 Add motor files
2020-10-31 Release CalkaBot v1
    [calkabot1.brd, calkabot1.sch, driver.brd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]
2020-10-31 Release CalkaBot v2.0
    [calkabot1.brd, calkabot1.sch, schemat.brd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]
2020-10-31 Repo for calkabot 3d0
    [driver.brd, driver.sch, encoder.brd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]
2020-11-04 Add in series stabilisators
    [driver.brd, driver.sch]
2020-11-09 added charger, and over charge protection
    [driver.brd, driver.sch]
2020-11-09 Added battery managment and motor drivers
    [driver.brd, driver.sch]
2020-11-09 added MPU6050 to board, and two motor drivers
    [driver.brd, driver.sch]
2020-11-09 new board
    [driver.brd]
2020-11-13 SD Card added
    [driver.brd, driver.sch]
2020-11-16 Added piheads for sensors. Added transoptors.
    [driver.brd, driver.sch]
2020-11-16 Pull up resistors to two I2C buses
    [driver.brd, driver.sch]
2020-11-16 ułożenie pinów i podpięcie sterowników rage quit
    [driver.brd, driver.sch]

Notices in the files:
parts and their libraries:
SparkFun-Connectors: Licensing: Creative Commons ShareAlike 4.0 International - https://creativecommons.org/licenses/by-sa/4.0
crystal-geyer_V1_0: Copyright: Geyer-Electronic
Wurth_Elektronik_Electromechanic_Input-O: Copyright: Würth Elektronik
